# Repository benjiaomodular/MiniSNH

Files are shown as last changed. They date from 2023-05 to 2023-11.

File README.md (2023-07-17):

# MiniSNH

An analog sample-and-hold module for Eurorack. It has random gates and trigger outputs that are in-sync with trigger input.

Turning the bias knob to one side makes the probability of the gates firing on one side higher than the other.

# Versions

## v1.0 - Initial Prototype
Does not work!!

- No mounting holes
- Holes for jacks too small
- Swapped negative and postiive power pins of U5 and U6
- Gate in for comparator was wired the wrong way (always high)

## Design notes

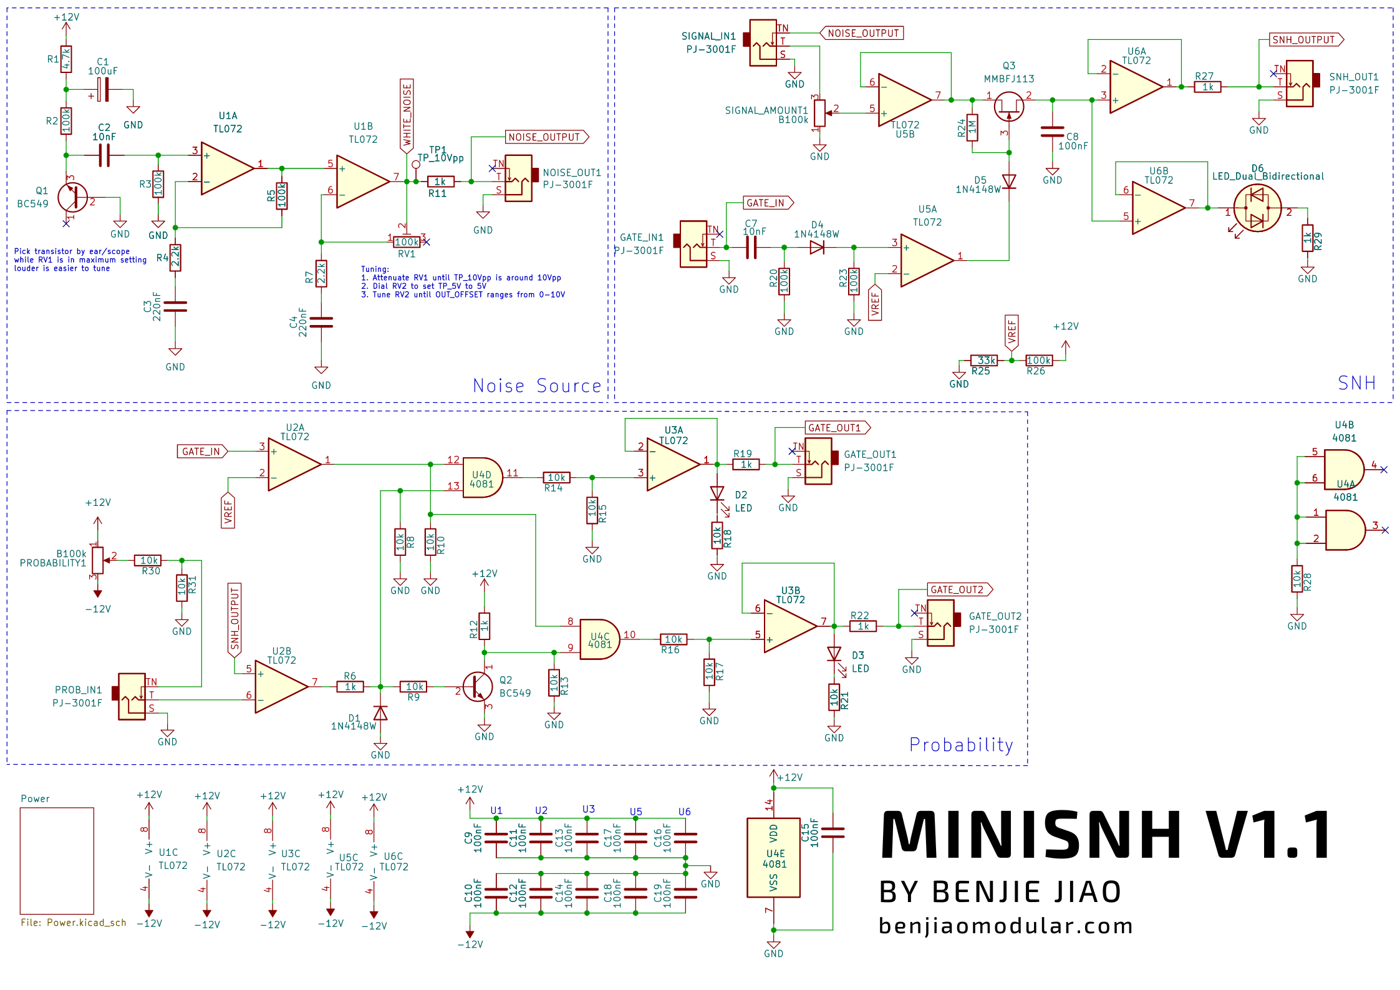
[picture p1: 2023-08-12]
MiniSNH v1.1 - Schematics.png

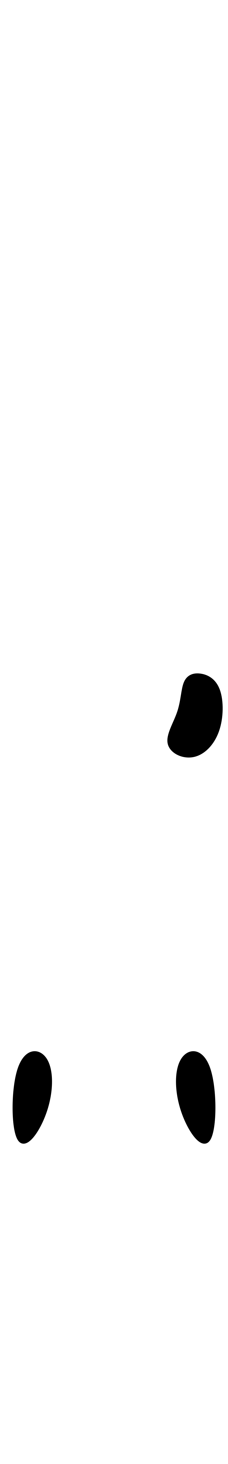
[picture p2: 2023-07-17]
MiniSNH v1.1/Inkscape Panel/.svg2shenzhen-cache/images/F.Mask_g1437.png

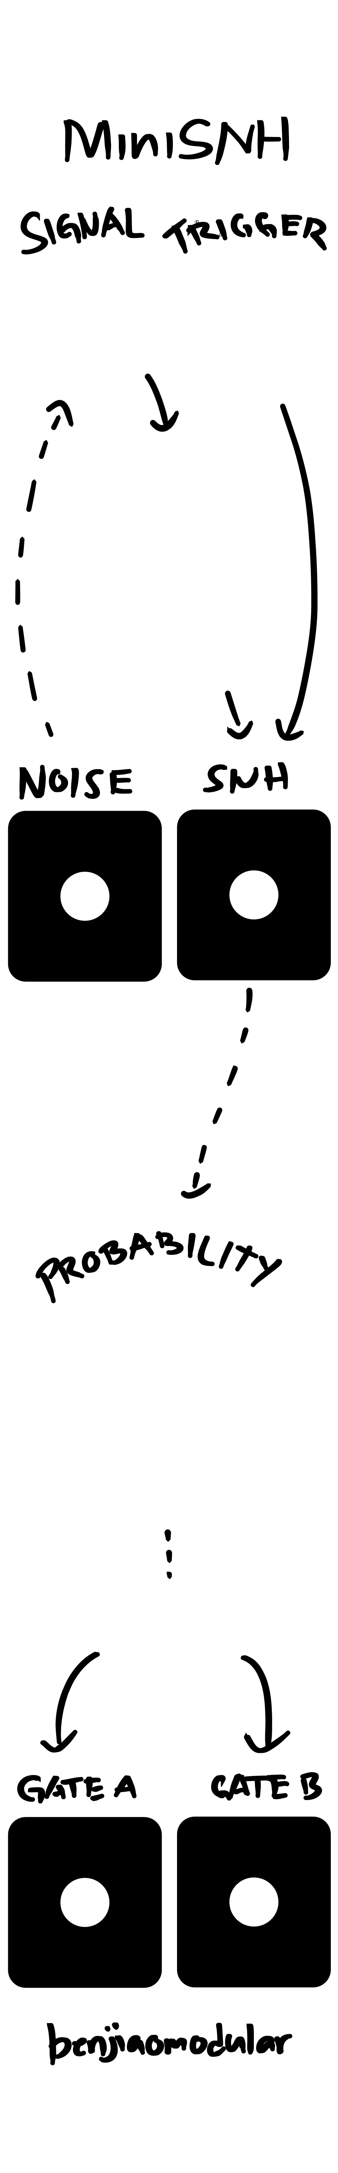
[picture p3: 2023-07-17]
MiniSNH v1.1/Inkscape Panel/.svg2shenzhen-cache/images/F.SilkS_g1439.png

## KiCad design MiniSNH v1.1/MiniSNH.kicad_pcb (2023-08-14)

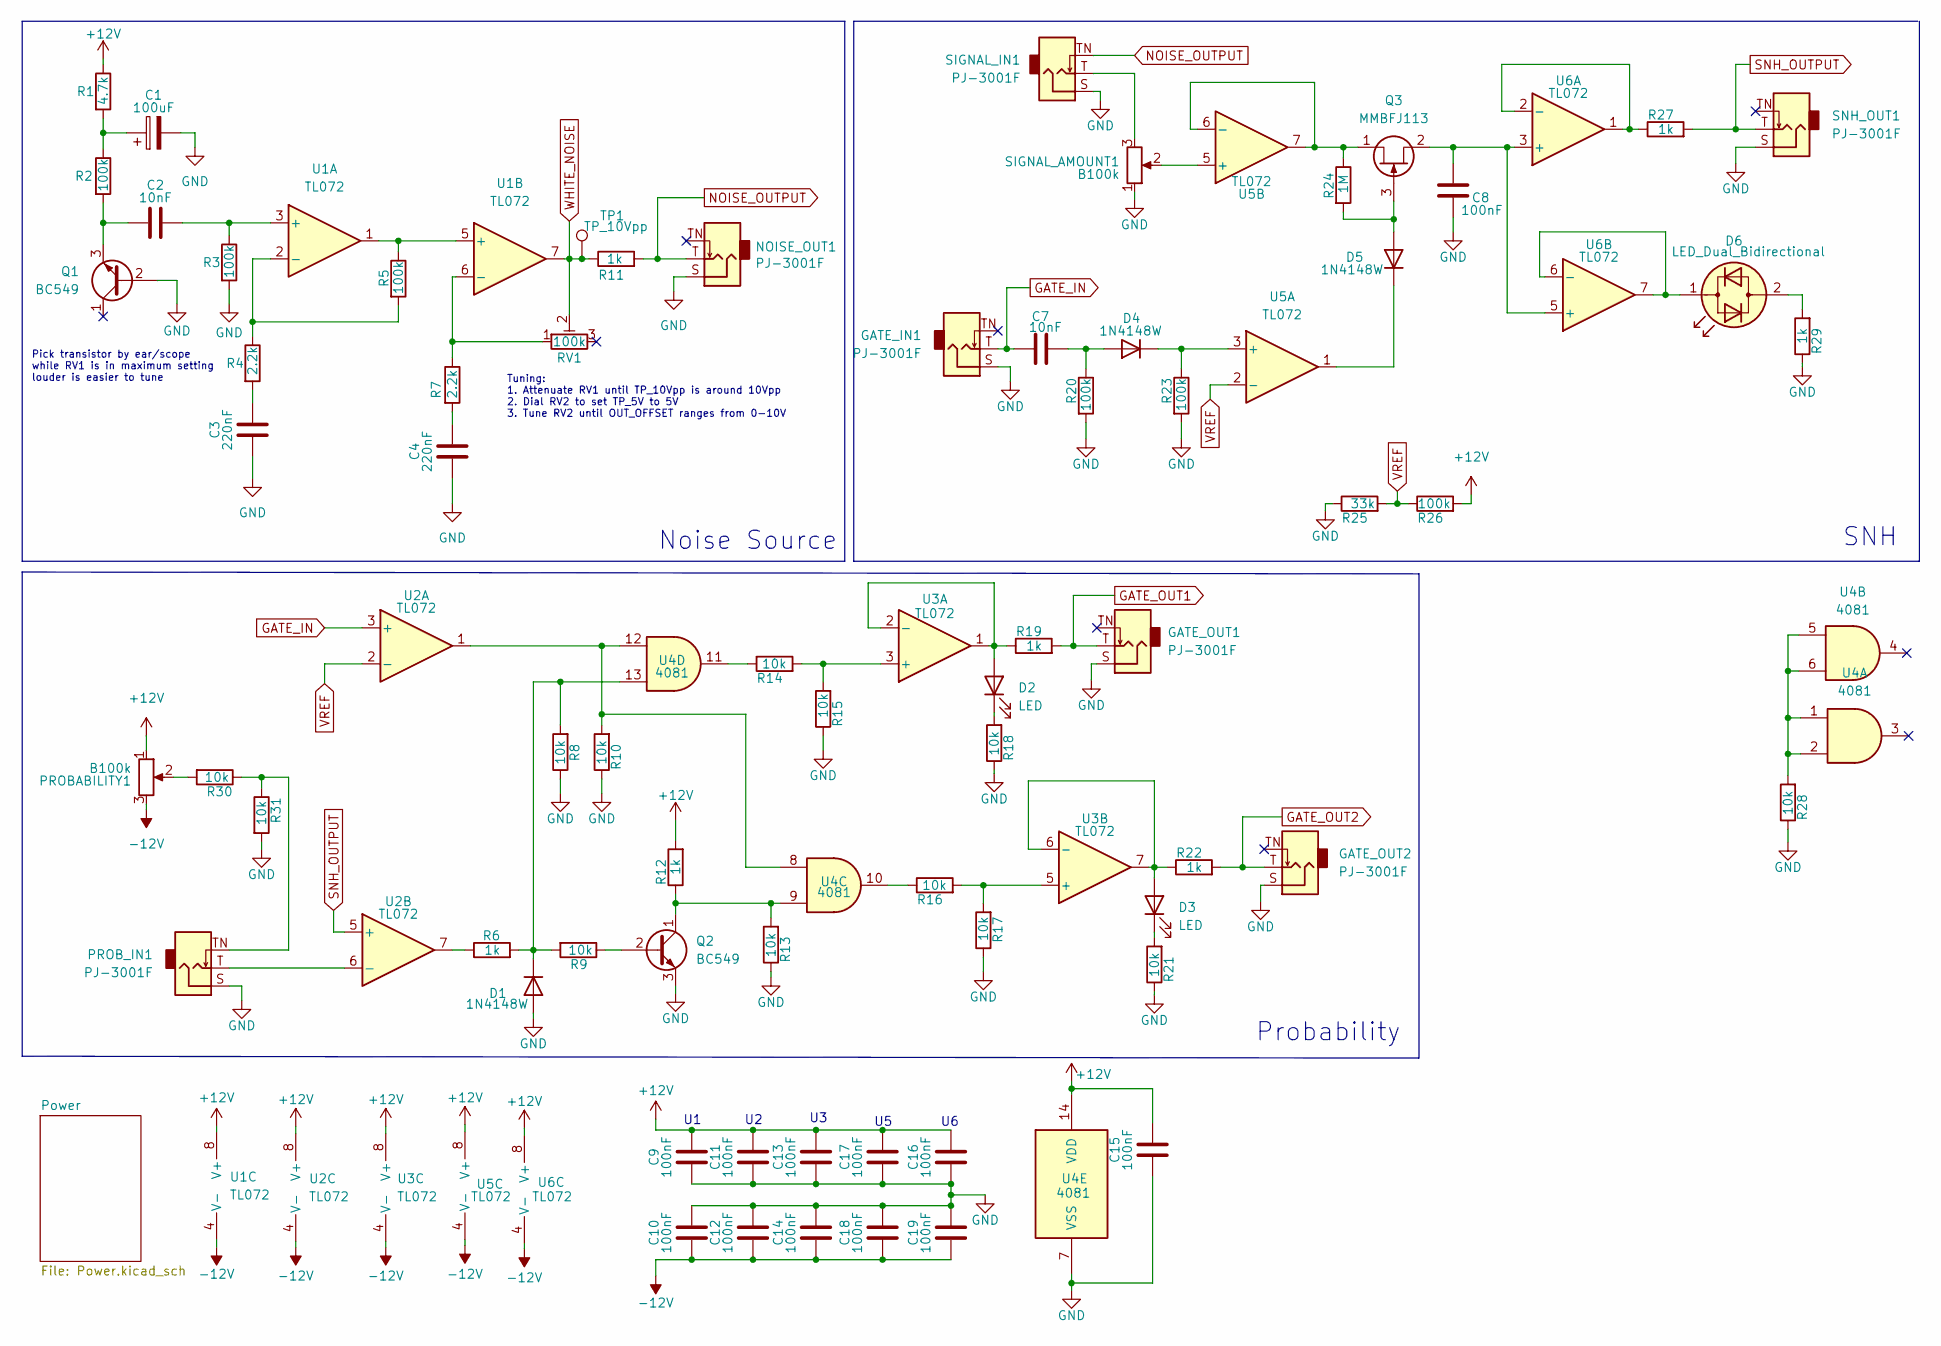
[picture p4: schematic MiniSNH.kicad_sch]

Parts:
C1: 100uF; Capacitor_Radial_D5.0mm_P2.5mm; Manufacturers Part Numb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 ESH107M010AC3AA
C2, C7: 10nF; C_0603_1608Metric_Pad1.08x0.95mm_HandSolder; Manufacturers Part Numb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 CC0603JRX7R9BB103
C3, C4: 220nF; C_0603_1608Metric_Pad1.08x0.95mm_HandSolder; Manufacturers Part Numb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 GCM188R71H224KA64D
C8, C9, C10, C11, C12, C13, C14, C15, C16, C17, C18, C19: 100nF; C_0603_1608Metric_Pad1.08x0.95mm_HandSolder; Manufacturers Part Numb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 CC0603JRX7R9BB104
D1, D4, D5: 1N4148W; D_SOD-123; Manufacturers Part Numb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 1N4148WQ-7-F
D2, D3: LED; LED_D3.0mm; Manufacturers Part Numb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 A-261
D6: LED_Dual_Bidirectional; LED_D3.0mm; Manufacturers Part Numb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 3ARG4HWC
GATE_IN1: PJ-3001F; AudioJack_3.5mm; Manufacturers Part Numb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 PJ-3001F
GATE_OUT1, GATE_OUT2: PJ-3001F; AudioJack_3.5mm; Manufacturers Part Numb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 PJ-3001F
NOISE_OUT1: PJ-3001F; AudioJack_3.5mm; Manufacturers Part Numb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 PJ-3001F
PROBABILITY1: B100k; Potentiometer_RV09_NoBracket; Manufacturers Part Numb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 RD901F-40-15R1-B100K
PROB_IN1: PJ-3001F; AudioJack_3.5mm; Manufacturers Part Numb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 PJ-3001F
Q1: BC549; TO-92_Inline_Wide; Manufacturers Part Numb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 BC548BTA
Q2: BC549; TO-92_Inline_Wide; Manufacturers Part Numb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 BC549BTF
Q3: MMBFJ113; SOT-23; Manufacturers Part Numb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 MMBFJ113
R1: 4.7k; R_0603_1608Metric_Pad0.98x0.95mm_HandSolder; Manufacturers Part Numb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 RC0603FR-074K7L
R2, R3, R5, R20, R23, R26: 100k; R_0603_1608Metric_Pad0.98x0.95mm_HandSolder; Manufacturers Part Numb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 RC0603FR-07100KL
R4, R7: 2.2k; R_0603_1608Metric_Pad0.98x0.95mm_HandSolder; Manufacturers Part Numb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 RK73B1JTTD222J
R6, R11, R12, R19, R22, R27, R29: 1k; R_0603_1608Metric_Pad0.98x0.95mm_HandSolder; Manufacturers Part Numb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 RC0603FR-071KL
R8, R9, R10, R13, R14, R15, R16, R17, R18, R21, R28, R30, R31: 10k; R_0603_1608Metric_Pad0.98x0.95mm_HandSolder; Manufacturers Part Numb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 AC0603FR-0710KL
R24: 1M; R_0603_1608Metric_Pad0.98x0.95mm_HandSolder; Manufacturers Part Numb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 RC0603FR-071ML
R25: 33k; R_0603_1608Metric_Pad0.98x0.95mm_HandSolder; Manufacturers Part Numb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 CR0603-FX-3302ELF
RV1: 100k; Potentiometer_Bourns_3266Y_Vertical; Manufacturers Part Numb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 PV36X104C01B00
SIGNAL_AMOUNT1: B100k; Potentiometer_RV09_NoBracket; Manufacturers Part Numb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 RD901F-40-15R1-B100K
SIGNAL_IN1: PJ-3001F; AudioJack_3.5mm; Manufacturers Part Numb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 PJ-3001F
SNH_OUT1: PJ-3001F; AudioJack_3.5mm; Manufacturers Part Numb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 PJ-3001F
TP1: TP_10Vpp; TestPoint_Pad_2.0x2.0mm
U1, U2, U3, U5, U6: TL072; SOIC-8_3.9x4.9mm_P1.27mm; Manufacturers Part Numb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 TL072CDT
U4: 4081; SOIC-14_3.9x8.7mm_P1.27mm; Manufacturers Part Numb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 CD4081BM96

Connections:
+12V: C9.2, C11.2, C13.2, C15.2, C16.2, C17.2, PROBABILITY1.1, R1.1, R12.2, R26.2, U1.8 (V+), U2.8 (V+), U3.8 (V+), U4.14 (VDD), U5.8 (V+), U6.8 (V+); also elsewhere on the board
-12V: C10.1, C12.1, C14.1, C18.1, C19.1, PROBABILITY1.3, U1.4 (V-), U2.4 (V-), U3.4 (V-), U5.4 (V-), U6.4 (V-); also elsewhere on the board
GATE_IN: C7.1, GATE_IN1.T, U2.3 (+)
GATE_OUT1: GATE_OUT1.T, R19.2
GATE_OUT2: GATE_OUT2.T, R22.2
GND: C1.2, C3.1, C4.1, C8.2, C9.1, C10.2, C11.1, C12.2, C13.1, C14.2, C15.1, C16.1, C17.1, C18.2, C19.2, D1.2 (A), GATE_IN1.S, GATE_OUT1.S, GATE_OUT2.S, NOISE_OUT1.S, PROB_IN1.S, Q1.2 (B), Q2.3 (E), R3.2, R8.1, R10.1, R13.1, R15.1, R17.1, R18.1, R20.2, R21.1, R23.2, R25.1, R28.1, R29.1, R31.2, SIGNAL_AMOUNT1.1, SIGNAL_IN1.S, SNH_OUT1.S, U4.7 (VSS); also elsewhere on the board
NOISE_OUTPUT: NOISE_OUT1.T, R11.2, SIGNAL_IN1.TN
unnamed: C1.1, R1.2, R2.1
unnamed: C2.1, Q1.3 (E), R2.2
unnamed: C2.2, R3.1, U1.3 (+)
unnamed: C3.2, R4.2
unnamed: C4.2, R7.2
unnamed: C7.2, D4.2 (A), R20.1
unnamed: C8.1, Q3.2 (S), U6.3 (+), U6.5 (+)
unnamed: D1.1 (K), R6.2, R8.2, R9.2, U4.13
unnamed: D2.1 (K), R18.2
unnamed: D2.2 (A), R19.1, U3.1, U3.2 (-)
unnamed: D3.1 (K), R21.2
unnamed: D3.2 (A), R22.1, U3.6 (-), U3.7
unnamed: D4.1 (K), R23.1, U5.3 (+)
unnamed: D5.1 (K), U5.1
unnamed: D5.2 (A), Q3.3 (G), R24.2
unnamed: D6.1 (KA), U6.6 (-), U6.7
unnamed: D6.2 (AK), R29.2
unnamed: PROBABILITY1.2, R30.2
unnamed: PROB_IN1.T, U2.6 (-)
unnamed: PROB_IN1.TN, R30.1, R31.1
unnamed: Q2.1 (C), R12.1, R13.2, U4.9
unnamed: Q2.2 (B), R9.1
unnamed: Q3.1 (D), R24.1, U5.6 (-), U5.7
unnamed: R4.1, R5.2, U1.2 (-)
unnamed: R5.1, U1.1, U1.5 (+)
unnamed: R6.1, U2.7
unnamed: R7.1, RV1.1, U1.6 (-)
unnamed: R10.2, U2.1, U4.8, U4.12
unnamed: R14.1, U4.11
unnamed: R14.2, R15.2, U3.3 (+)
unnamed: R16.1, U4.10
unnamed: R16.2, R17.2, U3.5 (+)
unnamed: R27.1, U6.1, U6.2 (-)
unnamed: R28.2, U4.1, U4.2, U4.5, U4.6
unnamed: SIGNAL_AMOUNT1.2, U5.5 (+)
unnamed: SIGNAL_AMOUNT1.3, SIGNAL_IN1.T
SNH_OUTPUT: R27.2, SNH_OUT1.T, U2.5 (+)
VREF: R25.2, R26.1, U2.2 (-), U5.2 (-)
WHITE_NOISE: R11.1, RV1.2, TP1.1, U1.7

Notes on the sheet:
Pick transistor by ear/scope while RV1 is in maximum setting louder is easier to tune
Probability
Noise Source
Tuning: 1. Attenuate RV1 until TP_10Vpp is around 10Vpp 2. Dial RV2 to set TP_5V to 5V 3. Tune RV2 until OUT_OFFSET ranges from 0-10V
SNH

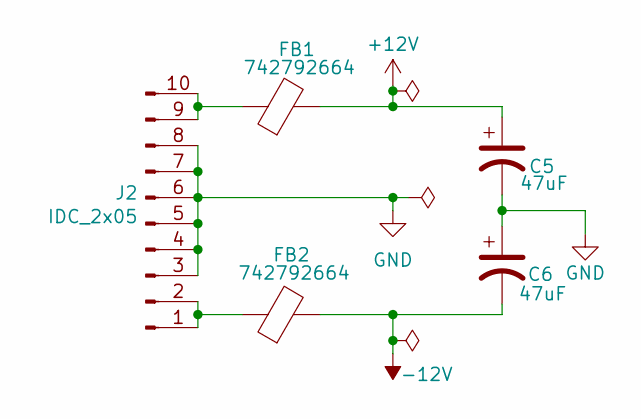
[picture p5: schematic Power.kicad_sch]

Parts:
C5, C6: 47uF; C_0805_2012Metric_Pad1.18x1.45mm_HandSolder; Manufacturers Part Numb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 GRM219R60J476ME44D
FB1, FB2: 742792664; C_0603_1608Metric_Pad1.08x0.95mm_HandSolder; Manufacturers Part Numb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 742792664
J2: IDC_2x05; IDC-Header_2x05_P2.54mm_Vertical; Manufacturers Part Numb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 X9555WV-2X05-6TV01; LCSC Part # C706914

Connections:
+12V: C5.1, FB1.2; also elsewhere on the board
-12V: C6.2, FB2.2; also elsewhere on the board
GND: C5.2, C6.1, J2.3, J2.4, J2.5, J2.6, J2.7, J2.8; also elsewhere on the board
unnamed: FB1.1, J2.9, J2.10
unnamed: FB2.1, J2.1, J2.2

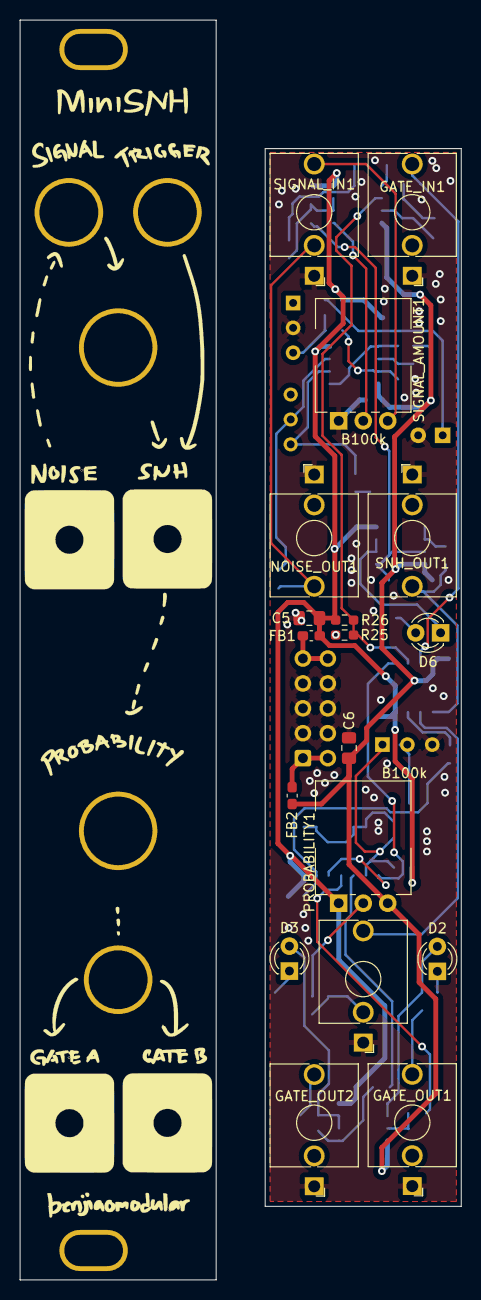
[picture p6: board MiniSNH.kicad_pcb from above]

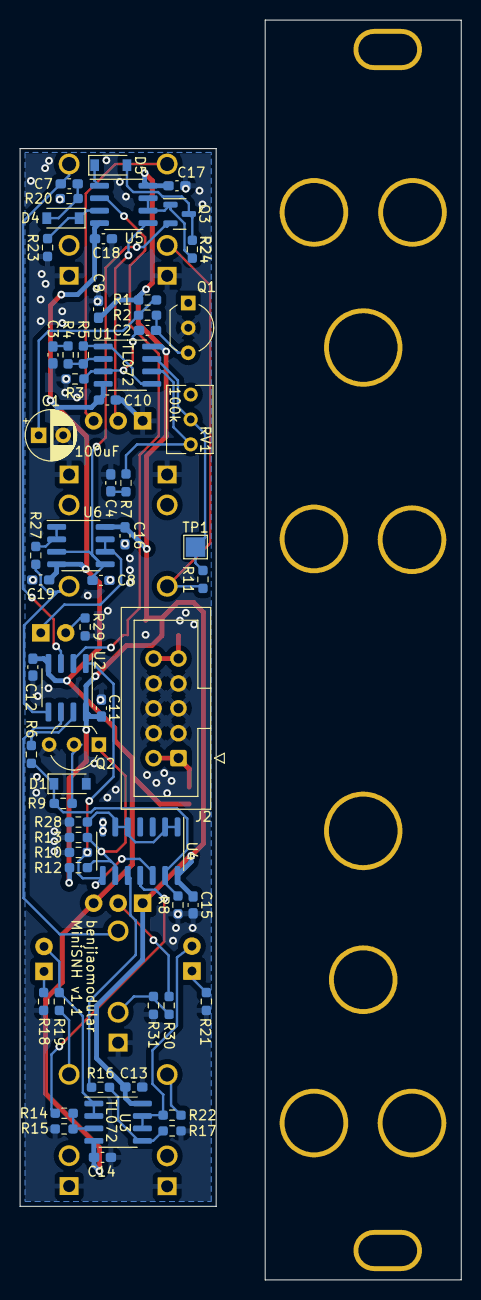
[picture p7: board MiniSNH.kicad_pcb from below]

Board: 2 copper layers, 20.0 x 107.9 mm, 79 parts (61 on the bottom side), 48 nets.

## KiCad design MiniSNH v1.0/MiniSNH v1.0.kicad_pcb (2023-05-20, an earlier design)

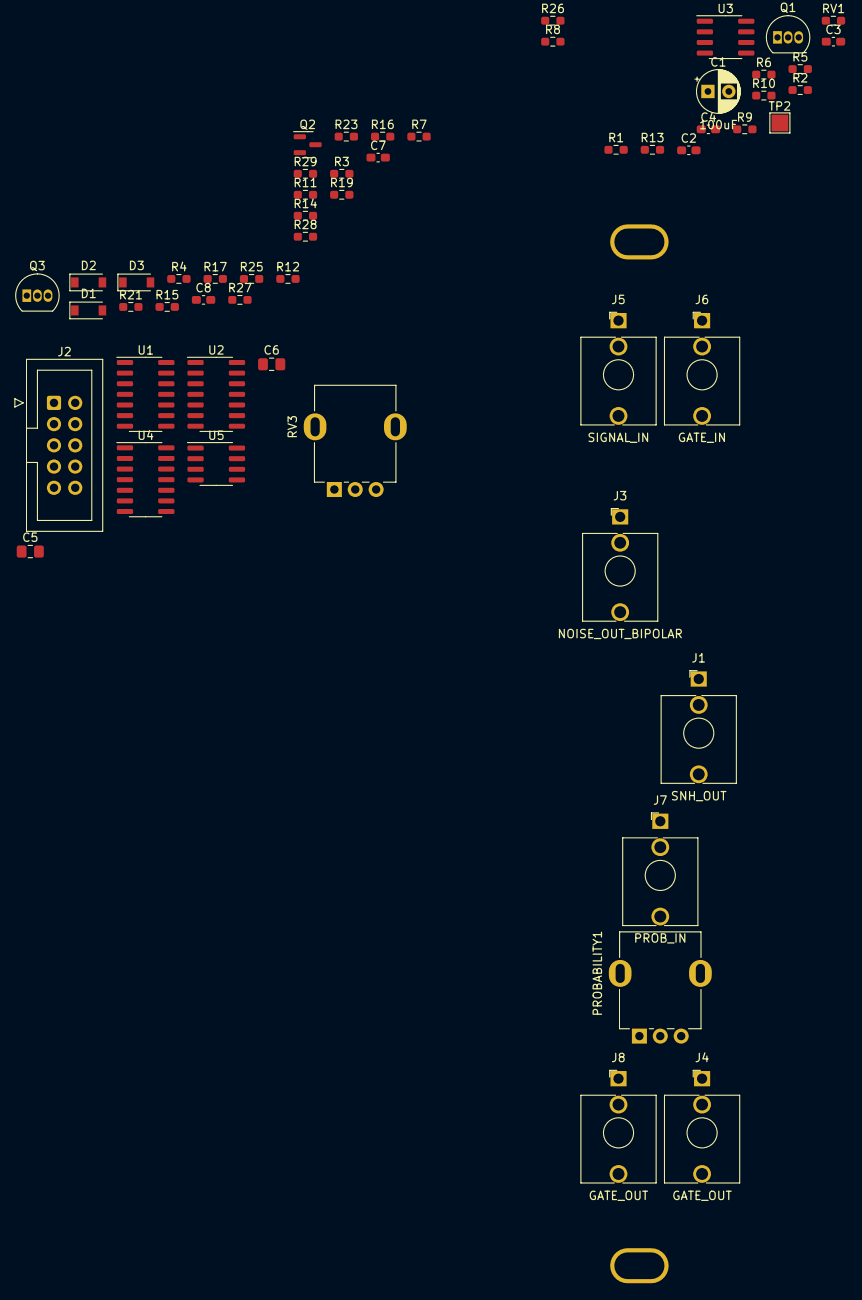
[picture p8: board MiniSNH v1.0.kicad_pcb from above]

Board: 2 copper layers, 56 parts (0 on the bottom side), 41 nets, no tracks yet.

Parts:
C1: 100uF; Capacitor_Radial_D5.0mm_P2.5mm
C2, C7: 10nF; C_0603_1608Metric_Pad1.08x0.95mm_HandSolder
C3, C4: 220nF; C_0603_1608Metric_Pad1.08x0.95mm_HandSolder
C5, C6: 22uF; C_0805_2012Metric_Pad1.18x1.45mm_HandSolder
C8: 100nF; C_0603_1608Metric_Pad1.08x0.95mm_HandSolder
D1, D2, D3: 1N4148W; D_SOD-123
J1: SNH_OUT; AudioJack_3.5mm
J2: IDC_2x05; IDC-Header_2x05_P2.54mm_Vertical
J3: NOISE_OUT_BIPOLAR; AudioJack_3.5mm
J4, J8: GATE_OUT; AudioJack_3.5mm
J5: SIGNAL_IN; AudioJack_3.5mm
J6: GATE_IN; AudioJack_3.5mm
J7: PROB_IN; AudioJack_3.5mm
PROBABILITY1: B100k; Potentiometer_RV09
Q1: BC548; TO-92_Inline
Q2: MMBFJ113; SOT-23
Q3: BC549; TO-92_Inline
R1: 4.7k; R_0603_1608Metric_Pad0.98x0.95mm_HandSolder
R2, R5, R8, R9: 100k; R_0603_1608Metric_Pad0.98x0.95mm_HandSolder
R3, R7, R12, R16, R17, R21, R25, R26, R27, R28: 10k; R_0603_1608Metric_Pad0.98x0.95mm_HandSolder
R4: 33k; R_0603_1608Metric_Pad0.98x0.95mm_HandSolder
R6, R10: 2.2k; R_0603_1608Metric_Pad0.98x0.95mm_HandSolder
R11, R13, R15, R19, R23, R29: 1k; R_0603_1608Metric_Pad0.98x0.95mm_HandSolder
R14: 1M; R_0603_1608Metric_Pad0.98x0.95mm_HandSolder
RV1: 100k; R_0603_1608Metric_Pad0.98x0.95mm_HandSolder
RV3: B100k; Potentiometer_RV09
TP2: TP_10Vpp; TestPoint_Pad_2.0x2.0mm
U1, U2: TL074; SOIC-14_3.9x8.7mm_P1.27mm
U3, U5: TL072; SOIC-8_3.9x4.9mm_P1.27mm
U4: 4081; SOIC-14_3.9x8.7mm_P1.27mm

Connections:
+12V: C5.1, J2.9, J2.10, PROBABILITY1.1, R1.1, R8.2, R23.2, U1.4 (V+), U2.4 (V+), U3.8 (V+)
-12V: C6.2, J2.1, J2.2, PROBABILITY1.3, U1.11 (V-), U2.11 (V-), U3.4 (V-), U5.4 (V-)
GATE_IN: J6.TN, U1.5 (+)
GND: C1.2, C3.1, C4.1, C5.2, C6.1, C8.2, D3.2 (A), J1.S, J2.3, J2.4, J2.5, J2.6, J2.7, J2.8, J3.S, J4.S, J5.S, J6.S, J7.S, J8.S, Q1.2 (B), Q3.3 (E), R3.2, R4.1, R5.2, R7.2, R12.1, R16.1, R17.1, R26.1, R28.1, RV3.1, U4.7 (VSS)
NOISE_OUTPUT: J3.T, J5.TN, R13.2
unnamed: C1.1, R1.2, R2.1
unnamed: C2.1, Q1.3 (E), R2.2
unnamed: C2.2, R5.1, U3.3 (+)
unnamed: C3.2, R6.2
unnamed: C4.2, R10.2
unnamed: C7.1, J6.T
unnamed: C7.2, D2.2 (A), R3.1
unnamed: C8.1, Q2.2 (S), U2.10 (+)
unnamed: D1.1 (K), U2.1
unnamed: D1.2 (A), Q2.3 (G), R14.2
unnamed: D2.1 (K), R7.1, U2.3 (+)
unnamed: D3.1 (K), R15.2, R21.2, U4.2
unnamed: J4.T, R19.2
unnamed: J5.T, RV3.3
unnamed: J7.T, U1.2 (-)
unnamed: J7.TN, PROBABILITY1.2
unnamed: J8.T, R29.2
unnamed: Q2.1 (D), R14.1, U2.13 (-), U2.14
unnamed: Q3.1 (C), R17.2, R23.1, U4.6
unnamed: Q3.2 (B), R21.1
unnamed: R6.1, R9.2, U3.2 (-)
unnamed: R9.1, U3.1, U3.5 (+)
unnamed: R10.1, RV1.1, U3.6 (-)
unnamed: R11.1, U2.8, U2.9 (-)
unnamed: R12.2, R16.2, U1.7, U4.1, U4.5
unnamed: R15.1, U1.1
unnamed: R19.1, U1.8, U1.9 (-)
unnamed: R25.1, U4.3
unnamed: R25.2, R26.2, U1.10 (+)
unnamed: R27.1, U4.4
unnamed: R27.2, R28.2, U1.12 (+)
unnamed: R29.1, U1.13 (-), U1.14
unnamed: RV3.2, U2.12 (+)
SNH_OUTPUT: J1.T, R11.2, U1.3 (+)
VREF: R4.2, R8.1, U1.6 (-), U2.2 (-)
WHITE_NOISE: R13.1, RV1.2, TP2.1, U3.7

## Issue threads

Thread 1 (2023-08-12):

part size issue in BOM

extremenerble, 2023-08-12:
I believe the part # you have in your BOM is for an 0805 sized cap, and the pads are certainly the same sized as all of your other 0603 parts.

Line 1, part # CC0805KRX7R9BB104 - 100nf cap.
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

extremenerble, 2023-08-12:
Ah, here's a quick fix. This is the 0603 version part # [CC0603JPX7R9BB103](https://www.mouser.com/ProductDetail/YAGEO/CC0603JPX7R9BB103?qs=AgBp2OyFlx8sWsQrSGxfow%3D%3D)

extremenerble, 2023-08-12:
Here's an alternative 0603 part [CC0603KPX7R9BB104](https://www.mouser.com/ProductDetail/YAGEO/CC0603KPX7R9BB104?qs=7s%252B3O6pAiyBs9nC6A1iRAA%3D%3D)

extremenerble, 2023-08-12:
Also you're missing a part # for the 2.2k resistor. Here's a possibility

[RC0603FR-072K2L](https://www.mouser.com/ProductDetail/YAGEO/RC0603FR-072K2L?qs=diQw95jMAeOQmNpe2MM%252BPw%3D%3D)

benjiao, 2023-08-14:
Hey thanks for bringing it up! Here's are the part numbers that I use:

- CC0603JRX7R9BB104
- RK73B1JTTD222J

benjiao, 2023-08-14:
Updated the BOM! Also added the 33k resistor and 100k trimmer.

https://benjiaomodular.com/boms/MiniSNH%20-%20v1.1.html

Closed 2023-08-14.

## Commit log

2023-05-20 initial push
    [MiniSNH v1.0.kicad_pcb, MiniSNH v1.0.kicad_sch, Noise.kicad_sch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]
2023-07-17 Added v1.1
    [MiniSNH v1.0 - Front-B_Cu.gbr, MiniSNH v1.0 - Front-B_Mask.gbr, MiniSNH v1.0 - Front-B_Paste.gbr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]
2023-08-12 Added gerber files for v1.1
    [MiniSNH v1.0 - Front-B_Cu.gbr, MiniSNH v1.0 - Front-B_Mask.gbr, MiniSNH v1.0 - Front-B_Paste.gbr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]
2023-08-12 Renamed broken gerber files
    [MiniSNH v1.0 - Front-B_Cu.gbr, MiniSNH v1.0 - Front-B_Mask.gbr, MiniSNH v1.0 - Front-B_Paste.gbr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]
2023-08-14 Updated bom with corrections in parts numbers
    [MiniSNH.kicad_pcb, MiniSNH.kicad_sch]
2023-08-14 Added footprints for 100k trimmer and 33k
    [MiniSNH.kicad_pcb, MiniSNH.kicad_sch]
2023-11-04 Troubleshooting v1.1
    [MiniAttenuMix.kicad_pcb]
